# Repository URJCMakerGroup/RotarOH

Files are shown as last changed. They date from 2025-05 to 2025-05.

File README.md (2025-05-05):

# RotarOH - Open Hardware Rotarod Test

RotarOH is an open hardware device designed to measure motor coordination and balance in rodents, such as rats and mice. This device is ideal for evaluating the effects of drugs, diseases, or brain damage in research studies.

It can move at speeds from 0 to 80 rpm.

The cost of the components is no more than TBD €, although for increased performance, precision components can be used at higher cost.

It is not too complicated to build. It should be simpler than building a 3D printer or CNC.

This is the first prototype of the Open Hardware Rotarod Test.

----

## License

TBD

----

## Bill of materials

TBD

----

## Assembly

[Assembly](./assembly/.)

----

## Firmware

[Firmware](./firmware/.)

----

## User guide

TBD

----

## Pictures

----

## Contributors

This work has been developed at [Universidad Rey Juan Carlos](https://www.urjc.es/) in Spain. It has been a collaboration between the Area of Electronic Technology and XXXX.

### Area of Electronic Technology:

- [Rubén Nieto](https://gestion2.urjc.es/pdi/ver/ruben.nieto)
- [Susana Borromeo](https://gestion2.urjc.es/pdi/ver/susana.borromeo)
- [Ángel Torrado](https://gestion2.urjc.es/pdi/ver/angel.torrado)
- [Felipe Machado](https://github.com/felipe-m/)

### XXXXX

### Students

Some students have collaborated in the project doing their capstone project in Industrial Engineering.

- [Víctor Alonso Gómez](https://github.com/Valonso6/TFGVictorAlonso): Initial project and finished first prototype.

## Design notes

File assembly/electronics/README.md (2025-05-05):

# Electronic Assembly

## 1. Tools

Since you will need to make your own cables, you will need a crimping tool like these:

- https://www.pololu.com/product/1928
- https://www.electrocomponentes.es/crimpadoras/917-crimpadora-sn-01bm-prensa-terminales-dupont-awg-28-20-crimper-tool.html
- https://solectroshop.com/es/crimpadoras/1822-sn-28b-dupont-terminal-crimpadora.html

There are some tutorials to make custom connectors:

- https://www.instructables.com/Dupont-Crimp-Tool-Tutorial/
- https://youtu.be/GkbOJSvhCgU
- https://youtu.be/K7Qb3DzIX3s

Also you may need a soldering tool and a soldering iron and solder, to solder the cables to the enstops.

## 2. Put the jumpers in the motor driver socket of RAMPS 1.4

RAMPS 1.4: [https://reprap.org/wiki/RAMPS_1.4](https://reprap.org/wiki/RAMPS_1.4)

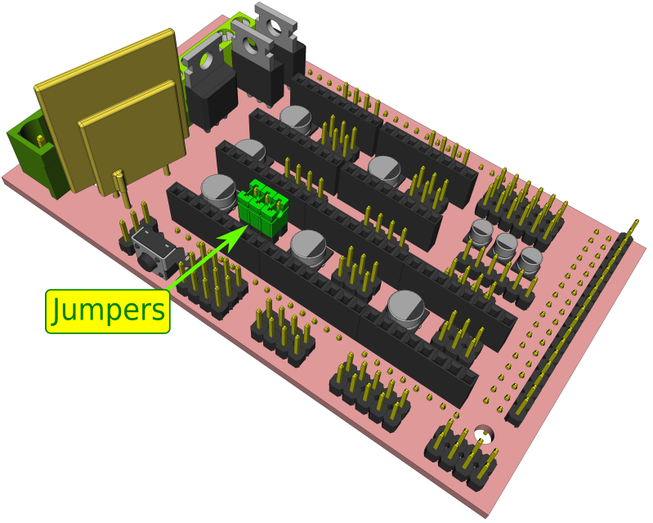
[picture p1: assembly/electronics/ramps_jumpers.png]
RAMPS-jumpers


## 3. Attach the RAMPS 1.4 to the Arduino board and attach the motor driver to the RAMPS

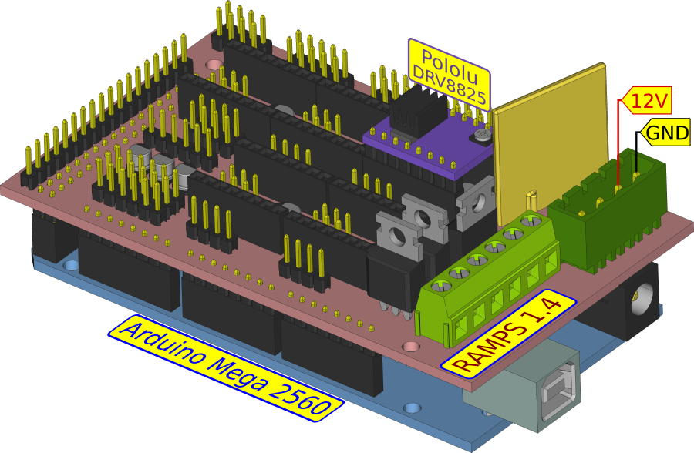
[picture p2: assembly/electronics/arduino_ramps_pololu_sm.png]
Arduino-RAMPS-DRV8825


Pay attention on the motor driver pinout, do not put it upside-down.
The Pololu DRV8825 and the A4988 have the trimmer in different positions

- Pololu DRV8825: [https://www.pololu.com/product/2133](https://www.pololu.com/product/2133)
- Pololu A4988: [https://www.pololu.com/product/1182](https://www.pololu.com/product/1182)

[Larger image: Arduino-RAMPS-DRV8825](./arduino_ramps_pololu.png)

## 4. Connect the elements as in the figure

If the power suppy is computer ATX, its green cable should be tied to ground (black)

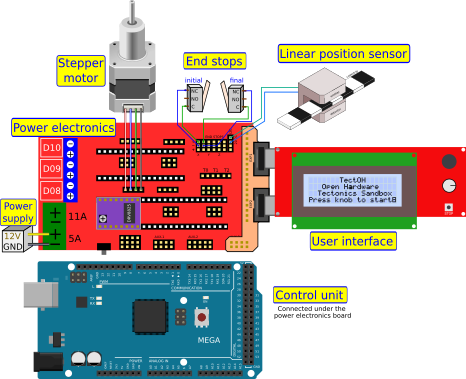
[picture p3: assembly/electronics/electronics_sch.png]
Electronics schematic


[Larger image of electronics schematic](./electronics_sch_big.png)

The section of the [optional components](../../optional/.) has more information on how to connect the optical sensor.

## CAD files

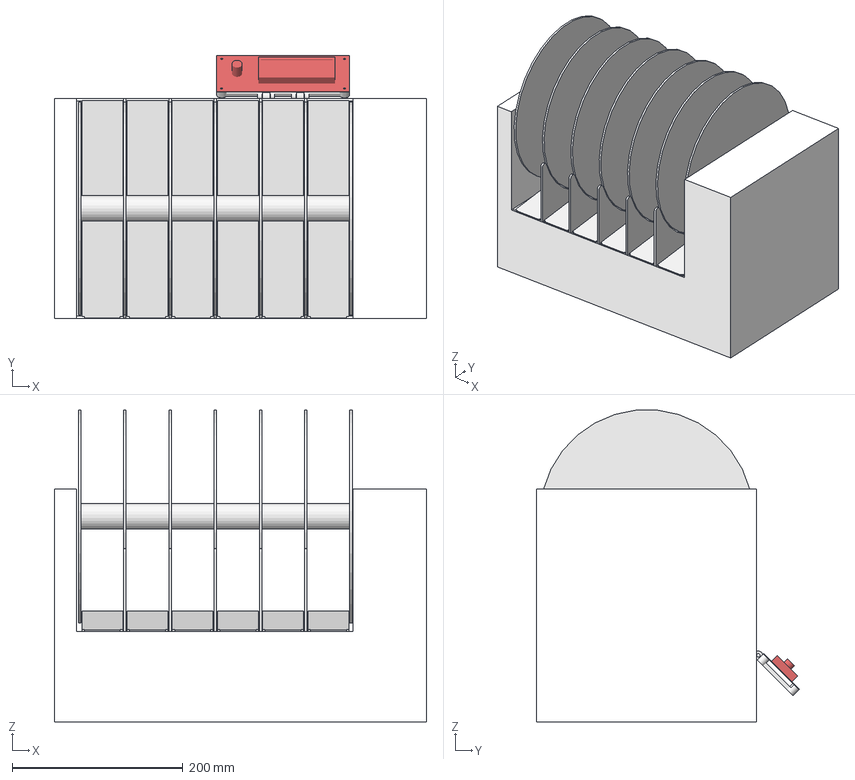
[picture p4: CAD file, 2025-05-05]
assembly/cad/freecad/RotarOH.FCStd
436.0 x 308.1 x 365.4 mm
Esqueleto
Separadores
Finales de carrera
Mecanismo tornillo+muelle
Plataformas_extraibles
Pantalla_LCD+Encoder rotatorio
Cubierta
Carriles
lcd-holder
lcd-hinge

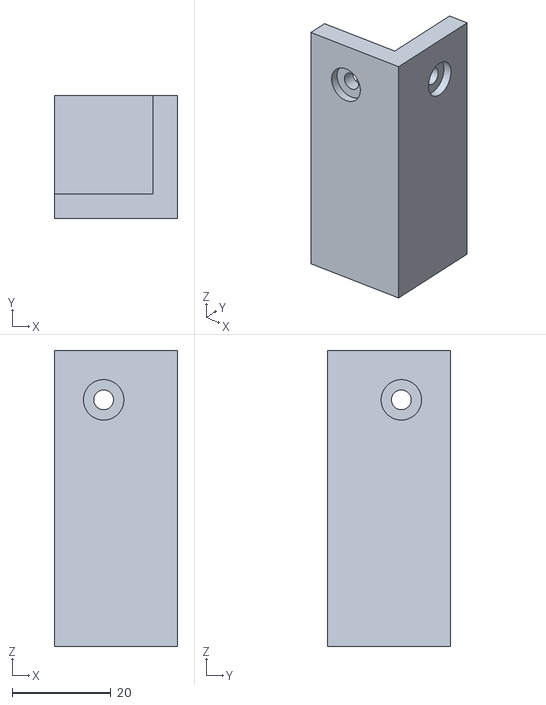
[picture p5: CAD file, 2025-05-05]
assembly/cad/stl/Pata.stl
25.0 x 25.0 x 60.0

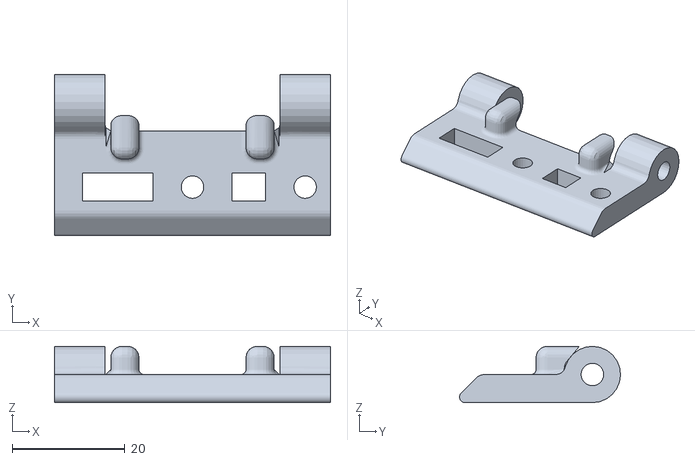
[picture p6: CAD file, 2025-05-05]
assembly/cad/stl/lcd-hinge.stl
49.0 x 28.6 x 10.0

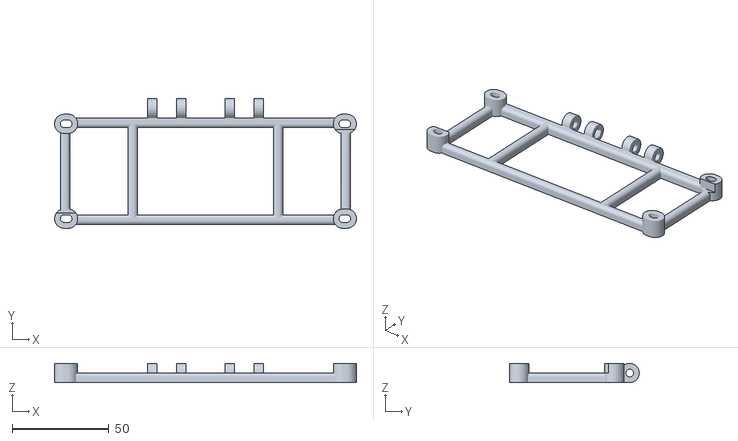
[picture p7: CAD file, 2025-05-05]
assembly/cad/stl/lcd-holder.stl
156.0 x 67.0 x 10.0

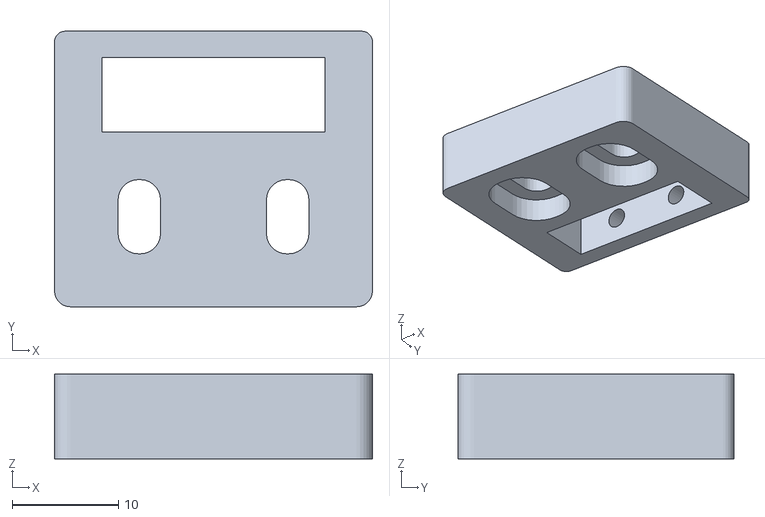
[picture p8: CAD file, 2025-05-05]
assembly/cad/stl/Abrazadera_final de carrera_.stl
30.0 x 26.0 x 8.00

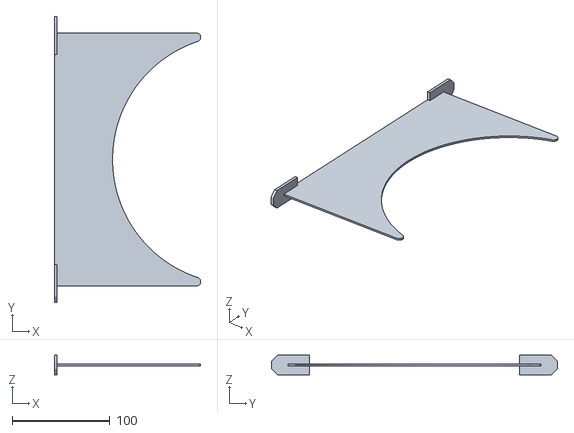
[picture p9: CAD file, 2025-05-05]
assembly/cad/stl/Separador.stl
149.5 x 292.0 x 20.0

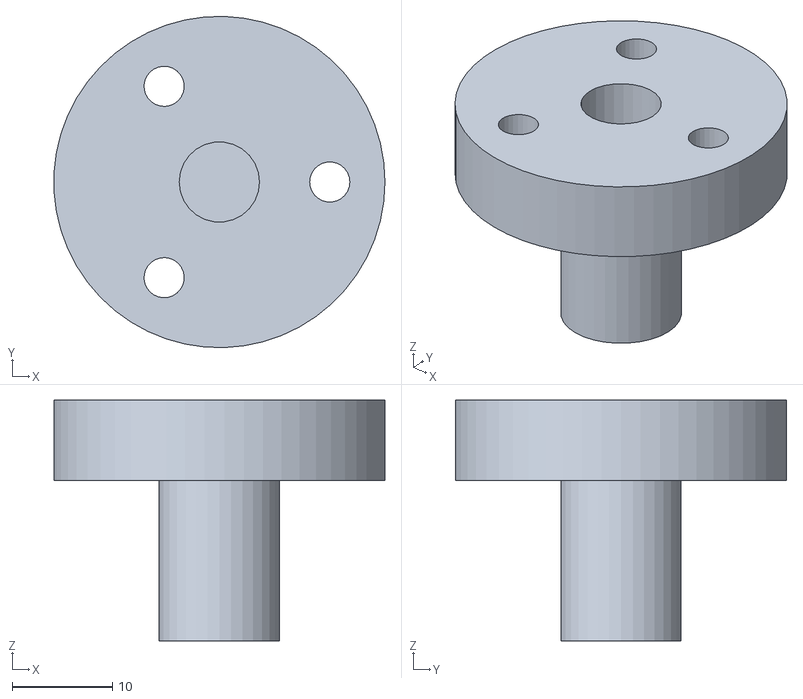
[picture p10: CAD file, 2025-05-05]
assembly/cad/stl/Abrazadera_tornillo.stl
33.0 x 33.0 x 24.0

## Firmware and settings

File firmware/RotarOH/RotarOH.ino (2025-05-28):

#include <TimerOne.h>       // Libreria del timer 1
#include <TimerThree.h>     // Libreria del timer 3
#include <TimerFour.h>      // Libreria del timer 4
#include <PinChangeInterrupt.h> //Librería para los pines PCINT

#include <LiquidCrystal.h>  // Libreria de la pantalla LCD
LiquidCrystal lcd(16, 17, 23, 25, 27, 29);

//Pines de la shield
#define LCD_PINS_RS 16      // LCD control conectado a GADGETS3D  shield LCDRS
#define LCD_PINS_ENABLE 17  // LCD enable pin conectado a GADGETS3D shield LCDE
#define LCD_PINS_D4 23      // LCD signal pin, conectado a GADGETS3D shield LCD4
#define LCD_PINS_D5 25      // LCD signal pin, conectado a GADGETS3D shield LCD5
#define LCD_PINS_D6 27      // LCD signal pin, conectado a GADGETS3D shield LCD6
#define LCD_PINS_D7 29      // LCD signal pin, conectado a GADGETS3D shield LCD7

#define X1_PIN 3         // PIN para el fin de carrera del carril 1 (1: presionado (true))
#define X2_PIN 2         // PIN para el fin de carrera del carril 2 (1: presionado (true))
#define X3_PIN 14        // PIN para el fin de carrera del carril 3 (1: presionado (true))
#define X4_PIN 15        // PIN para el fin de carrera del carril 4 (1: presionado (true))
#define X5_PIN 18        // PIN para el fin de carrera del carril 5 (1: presionado (true))
#define X6_PIN 19        // PIN para el fin de carrera del carril 6 (1: presionado (true))

#define X_STEP_PIN 54       // PIN de los pasos del controlador DRV8825 del motor paso a paso
#define X_DIR_PIN 55        // PIN de la direccion del controlador DRV8825 del motor paso a paso
#define X_ENABLE_PIN 38     // PIN del enable del controlador DRV8825 del motor paso a paso

#define BTN_EN1 31          // Encoder, conectado a GADGETS3D shield S_E1
#define BTN_EN2 33          // Encoder, cconectado a GADGETS3D shield S_E2
#define BTN_ENC 35          // Encoder Click, connected to Gadgets3D shield S_EC

float vectort_paso[]{9375,4688,3125,2344,1875,1563,1339,1172,1042,938,852,781,721,670,625,586,551,521,493,469,446,426,408,391,375,361,347,335,323,313,302,293,284,276,268,260,253,247,240,234,229,223,218,213,208,204,199,195,191,188,184,180,177,174,170,167,164,162,159,156,154,151,149,146,144,142,140,138,136,134,132,130,128,127,125,123,121.7};

unsigned long t_paso = 0;        // Variable en la que introducimos el tiempo de cada paso
volatile int nivel = LOW;        // Nivel del motor paso a paso

int raton1 = 0;    // Variable que define si la rata ha caido (1: rata caida)
int raton2 = 0;
int raton3 = 0;
int raton4 = 0;
int raton5 = 0;
int raton6 = 0;


volatile int v = 1;   // Inicializamos como 1 porque al coger un valor del veector_paso lo hacemos como vector_paso(v-1)
int vmax = 77;        // Velocidad máxima del sistema
int vmin = 1;         // Velocidad mínima del sistema
int vini = 0;         // Velocidad inicial de la rampa
int vfin = 0;         // Velocidad final de la rampa
int minuto = 0;
volatile int Ta = 0;  // Tasa de aceleración del sistema
int Tamax = 20;       // Tasa de aceleración máxima del sistema
int Tamin = 0;        // Tasa de aceleración mínima del sistema

int boton = 0;
bool btn_en1, btn_en2, btn_enc, btn_en1_prev, btn_en2_prev ;       // Variables de lectura directa del codificador giratorio mecanico
bool direccion = false;                                            // Direccion del codificador

int fila, columna, Modo = 0;                                       // Variable de fila y columna en la pantalla lcd
bool derecha, izquierda, pulsador = false;                         // Variables de lectura del codificador interpretadas
int i = 0;                                                         // Contador de pulsos
int volatile estado = 0;              // Variables del estado
int inicio = 0;                       // Variable para que el cronómetro comienze a contar
volatile int segundos = 0;

// SIGNOS CREADOS

byte empty[8] =
{
  B00000,
  B00100,
  B01010,
  B10001,
  B10001,
  B01010,
  B00100,
};
byte full[8] =
{
  B00000,
  B00100,
  B01110,
  B11111,
  B11111,
  B01110,
  B00100,
};



void setup() {

  pinMode(BTN_EN1, INPUT_PULLUP);     // Encoder 1
  pinMode(BTN_EN2, INPUT_PULLUP);     // Encoder 2
  pinMode(BTN_ENC, INPUT_PULLUP);     // Encoder Swith
           
  pinMode(X1_PIN, INPUT_PULLUP);   // Fin de carrera carril 1            
  pinMode(X2_PIN, INPUT_PULLUP);   // Fin de carrera carril 2
  pinMode(X3_PIN, INPUT_PULLUP);   // Fin de carrera carril 3
  pinMode(X4_PIN, INPUT_PULLUP);   // Fin de carrera carril 4
  pinMode(X5_PIN, INPUT_PULLUP);   // Fin de carrera carril 5
  pinMode(X6_PIN, INPUT_PULLUP);   // Fin de carrera carril 6

  attachInterrupt(digitalPinToInterrupt(X1_PIN),carril_1,RISING);      // Interrupciones de los finales de carrera
  attachInterrupt(digitalPinToInterrupt(X2_PIN),carril_2,RISING);
  attachPCINT(digitalPinToPCINT(X3_PIN),carril_3,CHANGE);
  attachPCINT(digitalPinToPCINT(X4_PIN),carril_4,CHANGE);
  attachInterrupt(digitalPinToInterrupt(X5_PIN),carril_5,RISING);
  attachInterrupt(digitalPinToInterrupt(X6_PIN),carril_6,RISING);

  lcd.begin(20, 4);   // 20 columnas y 4 filas

  pinMode(X_STEP_PIN , OUTPUT);
  pinMode(X_DIR_PIN , OUTPUT);
  pinMode(X_ENABLE_PIN , OUTPUT);

  btn_en1 , btn_en1_prev = digitalRead(BTN_EN1);
  btn_en2 , btn_en2_prev = digitalRead(BTN_EN2);
  btn_enc = digitalRead(BTN_ENC);

  lcd.createChar(0, empty);   // 0: numero de carácter; empty: matriz que contiene los pixeles del carácter
  lcd.createChar(1, full);    // 1: numero de carácter; full: matriz que contiene los pixeles del carácter

  digitalWrite(X_ENABLE_PIN , LOW);         // Habilitación a nivel bajo del motor paso a paso

}



void Temporizador() {
  
  if (inicio == 1) //                             <- INTERRUPCION CRONOMETRO
  {
    segundos++;
  }
  
}



void Motor()
{
  if (inicio == 1)
  {
    digitalWrite(X_STEP_PIN , nivel);
    if (nivel == LOW)   //                             <- INTERRUPCION MOVIMIENTO MOTOR TIEMPO PASO
    {       
       nivel = HIGH;
    }
    else
    {
       nivel = LOW;
    }  
  }
}



void aceleracion() 
{
  if (inicio == 1 and Modo == 1) //                                <- INTERRUPCION ACELERACION                       
  {
    minuto++;
    if (v<vfin and vini<vfin and minuto == 60)    // RAMPA
    {   
      v = v + Ta;
      minuto = 0;
    }
    else if (v>vfin and vini>vfin and minuto == 60)    //RAMPA INVERSA                               
    {
      v = v - Ta;
      minuto = 0;
    }
    else if (v == vfin and minuto == 60)
    {
      v = vfin;
      minuto = 0;
    }
  }
}

// INTERRUPCIONES DE FINAL DE CARRERA

void carril_1()
{
  raton1=1;  
}

void carril_2()
{
  raton2=1;  
}

void carril_3()
{
  raton3=1;  
}

void carril_4()
{
  raton4=1;  
}

void carril_5()
{
  raton5=1;  
}

void carril_6()
{
  raton6=1;  
}



void leer_pulso()
{
  btn_enc = digitalRead(BTN_ENC);

  if (btn_enc == false) //Detector de flanco del pulsador
  {
    i++;
  }
  if (i >= 30)
  {
    pulsador = true;
    i = 0;
    delay(200);
  }
  else
  {
    pulsador = false;
  }
}



void leer_encoder() 
{
  btn_en1 = digitalRead(BTN_EN1);
  btn_en2 = digitalRead(BTN_EN2);
  
  if (btn_en1 != btn_en1_prev || btn_en2 != btn_en2_prev)
  {
    if (btn_en2 == false & btn_en1 == false & btn_en2_prev == true & btn_en1_prev == false)
    {
      derecha = true;
      izquierda = false;
    }
    else if ( btn_en2 == false & btn_en1 == false & btn_en2_prev == false & btn_en1_prev == true )
    {
      derecha = false;
      izquierda = true;
    }
    else
    {
      derecha = false;
      izquierda = false;
    }
  }
  else
  {
    derecha = false;
    izquierda = false;
  }
  btn_en1_prev = btn_en1;
  btn_en2_prev = btn_en2;
}



void menu()         // Menú principal
{
  columna = 0;
  lcd.clear();
  lcd.setCursor(7,0);
  lcd.print("MENU");
  lcd.setCursor(1,1);
  lcd.print("Modo");
  lcd.setCursor(1,2);
  lcd.print("Velocidad");
  lcd.setCursor(1,3);
  lcd.print("Iniciar experimento");
  lcd.setCursor(0, 1);
  lcd.write(byte(0));
  lcd.setCursor(0, 2);
  lcd.write(byte(0));
  lcd.setCursor(0, 3);
  lcd.write(byte(0));
  lcd.setCursor(0, fila+1);
  lcd.write(byte(1)); 

}



void seleccion()      // Funcion que nos permite movernos a través de los menús
{
  switch (fila)
  {
    case 0: //seleccionar el modo
      if (pulsador == true  and columna < 3) // columna es una variable que avanza en horizontal por la pantalla, cuando vale 0 podemos cambia en vertical con derecha o izquierda, cuando no aumentamos la variable con la que estemos trabajando
      {
        columna++;
      }
      else if (pulsador == true and columna == 2) //hay 3 opciones
      {
        columna = 0;
      }    
      switch (columna)
      {
        case 0: //modo estandar
          if (derecha == true)
          {
            fila = 1;
            lcd.setCursor(0, 1);
            lcd.write(byte(0));
            lcd.setCursor(0, 2);
            lcd.write(byte(1));
            lcd.setCursor(0, 3);
            lcd.write(byte(0));
          }
        break;
        case 1:
          if (pulsador == true)
          {
            lcd.clear();
            lcd.setCursor(1,0);
            lcd.print("Selecciona el modo");
            lcd.setCursor(2,2);
            lcd.print("Estandar");
            lcd.setCursor(13,2);
            lcd.print("Rampa");
            lcd.setCursor(1,2);
            lcd.write(byte(1));
            lcd.setCursor(12,2);
            lcd.write(byte(0));
          }
          else if (derecha == true)
          {
            lcd.setCursor(1,2);
            lcd.write(byte(0));
            lcd.setCursor(12,2);
            lcd.write(byte(1));
            columna=3;
          }  
        break;
        case 2:    
          if (pulsador == true)
          {
            Modo=0;
            estado=0;
          }
          else if (derecha == true)
          {
            lcd.setCursor(1,2);
            lcd.write(byte(0));
            lcd.setCursor(12,2);
            lcd.write(byte(1));
            columna=3;
          }  
        break;
        case 3: //modo rampa
          if (pulsador == true)
          {
          Modo=1;
          estado=0;
          }
          else if (izquierda == true)
          {
            lcd.setCursor(1,2);
            lcd.write(byte(1));
            lcd.setCursor(12,2);
            lcd.write(byte(0));
            columna=1;
          }
        break;
      }   
    break;
    case 1: // Velocidad
      if (pulsador == true  and columna < 4) // columna es una variable que avanza en horizontal por la pantalla, cuando vale 0 podemos cambia en vertical con derecha o izquierda, cuando no aumentamos la variable con la que estemos trabajando
      {
        columna++;
      }
      else if (pulsador == true and columna == 4)
      {
        columna = 0;
        estado=0;
      }
      switch (columna)
      {
        case 0:
          if (derecha == true)
          {
            fila = 2;
            lcd.setCursor(0, 1);
            lcd.write(byte(0));
            lcd.setCursor(0, 2);
            lcd.write(byte(0));
            lcd.setCursor(0, 3);
            lcd.write(byte(1));
          }
          else if (izquierda == true)
          {
            fila = 0;
            lcd.setCursor(0, 1);
            lcd.write(byte(1));
            lcd.setCursor(0, 2);
            lcd.write(byte(0));
            lcd.setCursor(0, 3);
            lcd.write(byte(0));
          }
        break;
        case 1:
          if (pulsador == true and Modo == 0)
          {
            lcd.clear();
            lcd.setCursor(3,0);
            lcd.print("Selecciona la");
            lcd.setCursor(5,1);
            lcd.print("velocidad");
            lcd.setCursor(2,3);
            lcd.print("Velocidad:00");
            lcd.setCursor(14,3);
            lcd.print("rpm");
          }
    
          if (v<vmax and derecha == true and Modo == 0)    
          {
            v++;
          }
          else if (v>vmin and izquierda == true and Modo == 0)
          {
            v--;
          }
          else if (v<10 and Modo == 0)
          {
            lcd.setCursor(12,3);
            lcd.print("0");
            lcd.setCursor(13,3);
            lcd.print(v);
          }
          else if (v>=10 and Modo == 0)
          {
            lcd.setCursor(12,3);
            lcd.print(v);
          }
          
          else if (pulsador == true and Modo == 1)
          {
            lcd.clear();
            lcd.setCursor(0,0);
            lcd.print("Escoge la velocidad");
            lcd.setCursor(0,1);
            lcd.print("inicial y final y la");
            lcd.setCursor(0,2);
            lcd.print("tasa de aceleracion");
            lcd.setCursor(5,3);
            lcd.print("por minuto");
          }
           
        break;
        case 2:
          if (pulsador == true and Modo == 0)
          {
            estado=0;
            columna=0;

          }
          else if (pulsador == true and Modo == 1)
          {
            lcd.clear();
            lcd.setCursor(1,1);
            lcd.print("Vini:");
            lcd.setCursor(6,1);
            lcd.print("00:");
            lcd.setCursor(8,1);
            lcd.print("rpm");
            lcd.setCursor(1,2);
            lcd.print("Vfin:");
            lcd.setCursor(6,2);
            lcd.print("00:");
            lcd.setCursor(8,2);
            lcd.print("rpm");
            lcd.setCursor(1,3);
            lcd.print("Tasa Ac.:");
            lcd.setCursor(10,3);
            lcd.print("00");
            lcd.setCursor(12,3);
            lcd.print("rpm/m");
            lcd.setCursor(0,1);
            lcd.write(byte(1));
            lcd.setCursor(0,2);
            lcd.write(byte(0));
            lcd.setCursor(0,3);
            lcd.write(byte(0));
          }
          if (v<vmax and derecha == true and Modo == 1)
          {
            v++;
            vini = v;
          }
          else if (v>vmin and izquierda == true and Modo == 1)
          {
            v--;
            vini = v;
          } 
          if (v<10 and Modo == 1)
          {
            lcd.setCursor(6,1);
            lcd.print("0");
            lcd.setCursor(7,1);
            lcd.print(v);
          }
          else if (v>=10 and Modo == 1)
          {
            lcd.setCursor(6,1);
            lcd.print(v);
          }
            
        break;
        case 3:
          lcd.setCursor(0,1);
          lcd.write(byte(0));
          lcd.setCursor(0,2);
          lcd.write(byte(1));
          lcd.setCursor(0,3);
          lcd.write(byte(0));
          if (v<vmax and derecha == true and Modo == 1)
          {
            v++;
            vfin = v;
          }
          else if (v>vmin and izquierda == true and Modo == 1)
          {
            v--;
            vfin = v;
          } 
          if (v<10 and Modo == 1)
          {
            lcd.setCursor(6,2);
            lcd.print("0");
            lcd.setCursor(7,2);
            lcd.print(v);
          }
          else if (v>=10 and Modo == 1)
          {
            lcd.setCursor(6,2);
            lcd.print(v);
          }
        break;
        case 4:
          if (pulsador == true and Modo == 1)
          {
            lcd.setCursor(0,1);
            lcd.write(byte(0));
            lcd.setCursor(0,2);
            lcd.write(byte(0));
            lcd.setCursor(0,3);
            lcd.write(byte(1));
          }
          if (Ta<Tamax and derecha == true)
          {
            Ta++;
          }
          else if (Ta>Tamin and izquierda == true)
          {
            Ta--;
          } 
          if (Ta<10)
          {
            lcd.setCursor(10,3);
            lcd.print("0");
            lcd.setCursor(11,3);
            lcd.print(Ta);
          }
          else if (Ta>=10)
          {
            lcd.setCursor(10,3);
            lcd.print(Ta);
          }          
        break;
      }
    break;
    case 2: //Iniciar experimento
      if (pulsador == true)
      {
        lcd.clear();
        estado = 2;
        
      }
      else if (izquierda == true)
      {
        fila = 1;
        lcd.setCursor(0, 1);
        lcd.write(byte(0));
        lcd.setCursor(0, 2);
        lcd.write(byte(1));
        lcd.setCursor(0, 3);
        lcd.write(byte(0));
      }
    break;
  }
}

void espera()    // Display de espera para la colocación de las ratas
{
  lcd.setCursor(5,0);
  lcd.print("Prepare el");
  lcd.setCursor(4,1);
  lcd.print("experimento");
  lcd.setCursor(2,2);
  lcd.print("y manten pulsado");
  lcd.setCursor(3,3);
  lcd.print("para continuar");
  if (pulsador == true)
  {
    lcd.clear();
    estado = 3;
  }
}
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
void loop() {
  switch (estado)
  {
    case 0:             // Menú principal
      raton1 = 0;
      raton2 = 0;
      raton3 = 0;
      raton4 = 0;
      raton5 = 0;
      raton6 = 0;
      menu();
      estado = 1;
    break;

    case 1:            // Selección de variables a traves del menú
      leer_pulso();
      leer_encoder();
      seleccion();
    break;

    case 2:             // Display del mensaje de preparación del experimento
      leer_pulso();
      leer_encoder();
      espera();
    break;
   
    case 3:             // Display de la pantalla de información sobre el experimento según el modo escogido
      if (Modo == 0)    // Modo Estandar
      {
        lcd.setCursor(0,0);
        lcd.print("000s");
        lcd.setCursor(0,1);
        lcd.print("00rpm"); 
        lcd.setCursor(6,0);
        lcd.print("000s"); 
        lcd.setCursor(6,1);
        lcd.print("00rpm");  
        lcd.setCursor(12, 0);
        lcd.print("000s");
        lcd.setCursor(12, 1);
        lcd.print("00rpm");
        lcd.setCursor(3, 2);
        lcd.print("000s");
        lcd.setCursor(3, 3);
        lcd.print("00rpm");
        lcd.setCursor(9, 2);
        lcd.print("000s"); 
        lcd.setCursor(9, 3);
        lcd.print("00rpm");
        lcd.setCursor(15, 2);
        lcd.print("000s");
        lcd.setCursor(15, 3);
        lcd.print("00rpm");
        
      }
      else if (Modo == 1) // Modo Rampa
      {
        v = vini;
        lcd.setCursor(0,0);
        lcd.print("000s");
        lcd.setCursor(0,1);
        lcd.print("00rpm"); 
        lcd.setCursor(6,0);
        lcd.print("000s"); 
        lcd.setCursor(6,1);
        lcd.print("00rpm");  
        lcd.setCursor(12, 0);
        lcd.print("000s");
        lcd.setCursor(12, 1);
        lcd.print("00rpm");
        lcd.setCursor(3, 2);
        lcd.print("000s");
        lcd.setCursor(3, 3);
        lcd.print("00rpm");
        lcd.setCursor(9, 2);
        lcd.print("000s");
        lcd.setCursor(9, 3);
        lcd.print("00rpm");
        lcd.setCursor(15, 2);
        lcd.print("000s");
        lcd.setCursor(15, 3);
        lcd.print("00rpm");
      }
      estado = 4;
    break;

    case 4:           // Inicio del experimento
      inicio = 1;
      experimento();
      leer_pulso();
      leer_encoder();
    break;

    case 5:           // Display de resultados
      inicio = 0;
      leer_pulso();
      if (pulsador == true)
      {
        Ta = 0;
        fila = 0;
        v = 0;
        estado = 0;
      }
    break;
  }

}

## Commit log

2025-05-05 Create Vector velocidad.txt
2025-05-07 Minor corrections on RotarOH.ino
    [RotarOH.ino]
2025-05-28 minor corrections in RotarOH.ino
    [RotarOH.ino]
